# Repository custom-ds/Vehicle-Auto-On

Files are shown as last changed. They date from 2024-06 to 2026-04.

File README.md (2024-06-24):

# Vehicle Auto-On #

## Source ##

### Configuring the Dev Environment ###
Install Platform IO in Visual Studio Code

Use the jtag2updi

https://dev.to/dariocasciato/attiny85-programming-your-complete-guide-with-arduino-and-platformio-37do

https://www.electronics-lab.com/project/programming-attiny10-platform-io-ide/

### Programming ###

With the Arduion programmer board loaded with the jtag2updi software, and the Pin 6 from the Arduino connected to the Reset
line on the ATTiny404, you can Build and Program directly inside of the Visual Studio Code.

To build, go to the bottom-left part of the screen to the Status Bar area of VSCode, and there should be some little icons
that Platform IO installed. The Checkmark icon is the Build option, and will compile/build the code that is written.

Once it compiles successfully, there is a second icon that is a right-arrow to click, which will utilize the Arduino
programmer to program the ATTiny via UPDI.

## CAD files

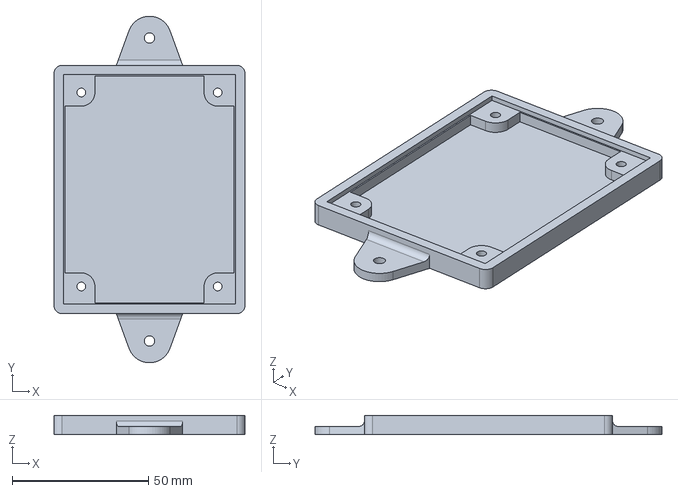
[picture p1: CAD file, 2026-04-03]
Case/Vehicle Power.FCStd
70.0 x 127.0 x 7.00 mm

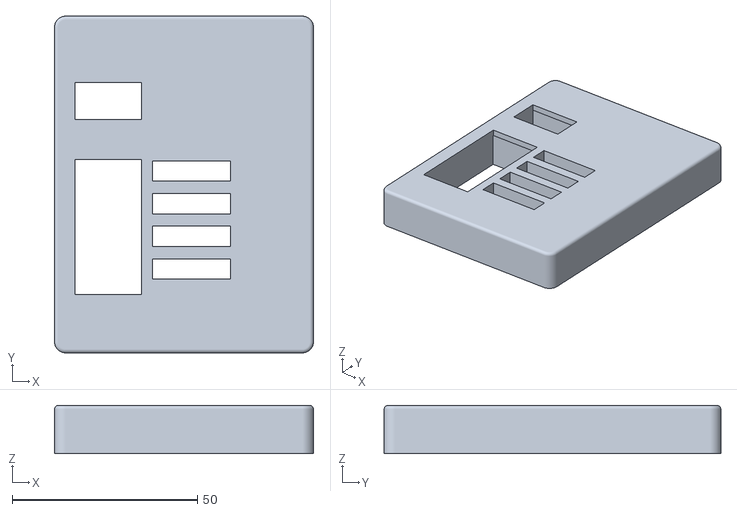
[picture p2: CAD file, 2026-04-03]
Case/housing-top - no cutouts.stl
70.0 x 91.0 x 13.0

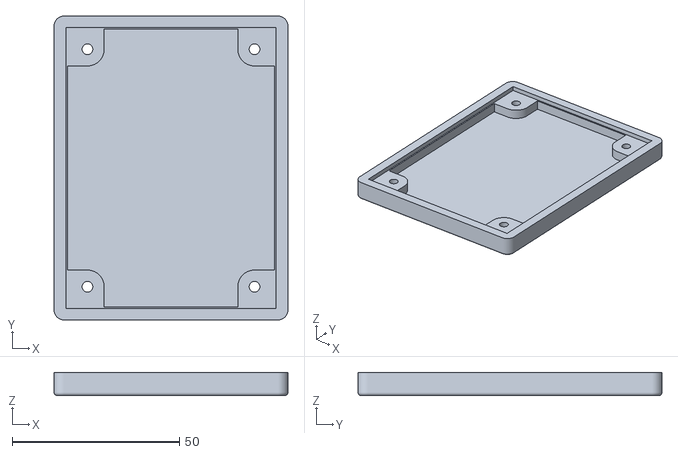
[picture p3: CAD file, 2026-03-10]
Case/housing-bottom.stl
70.0 x 91.0 x 7.00

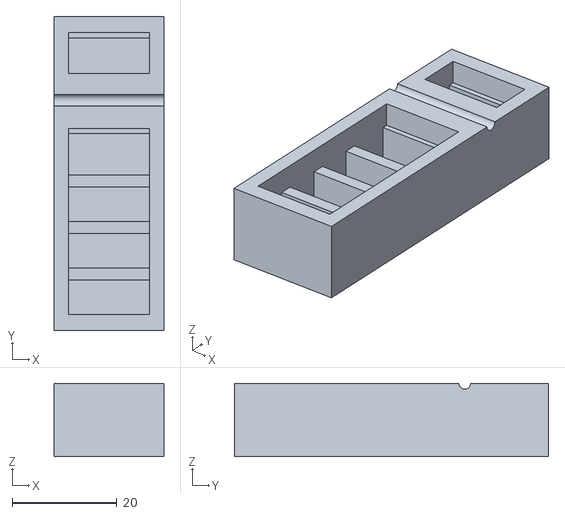
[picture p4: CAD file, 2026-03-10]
Case/alignment-jig.stl
21.0 x 60.0 x 14.0

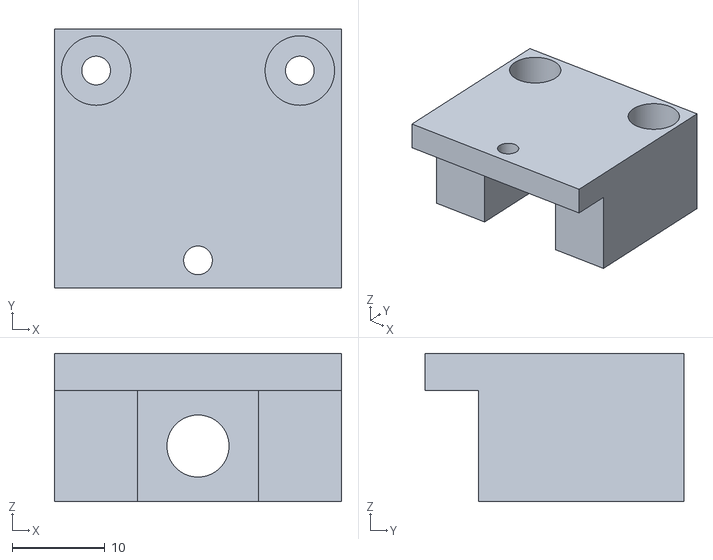
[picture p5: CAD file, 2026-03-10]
Case/switch-front.stl
31.0 x 28.0 x 16.0

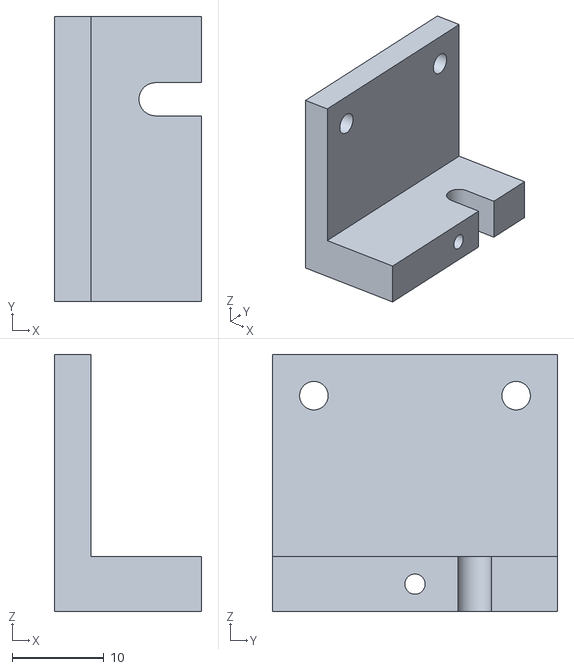
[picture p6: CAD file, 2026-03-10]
Case/switch-back.stl
16.0 x 31.0 x 28.0

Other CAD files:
Case/housing-bottom-with-tab.stl
Case/housing-top.stl

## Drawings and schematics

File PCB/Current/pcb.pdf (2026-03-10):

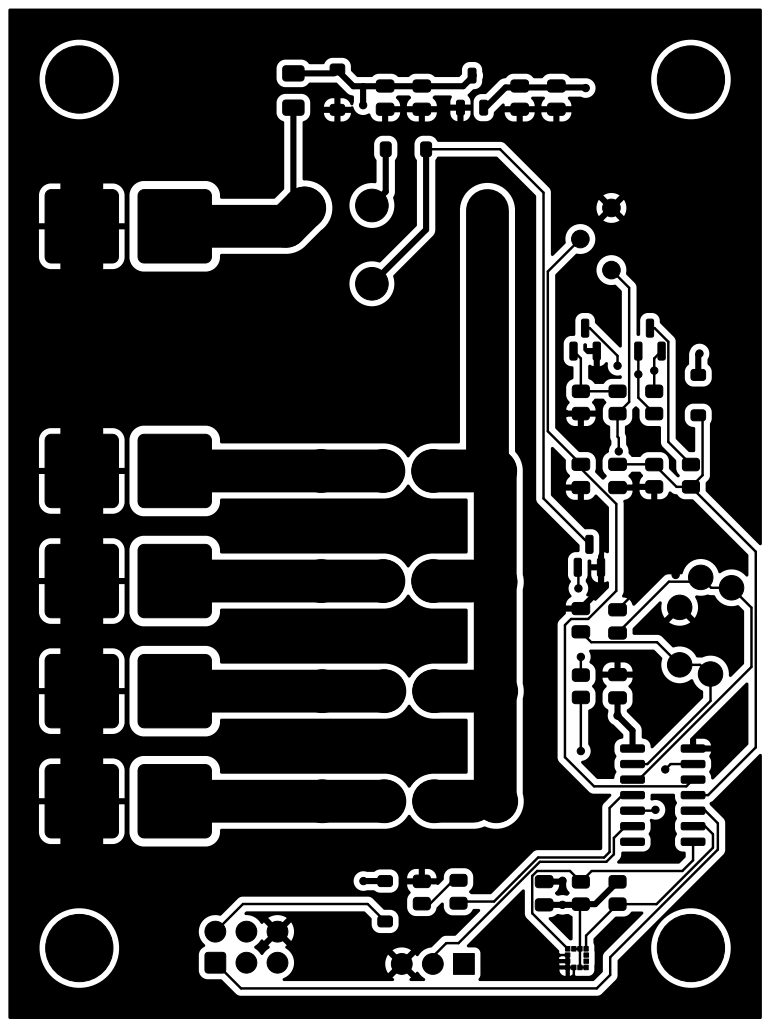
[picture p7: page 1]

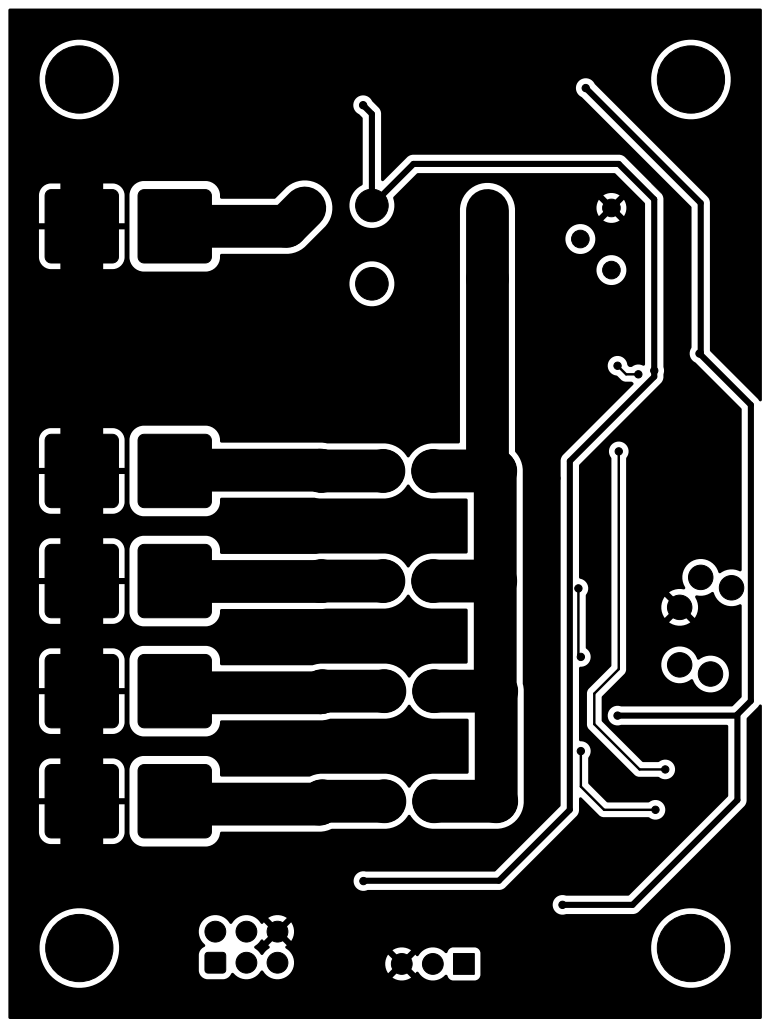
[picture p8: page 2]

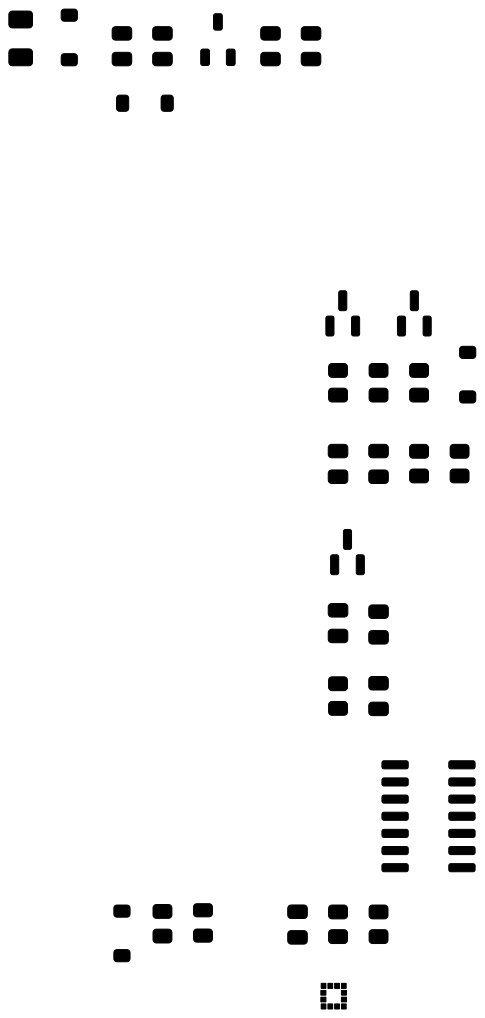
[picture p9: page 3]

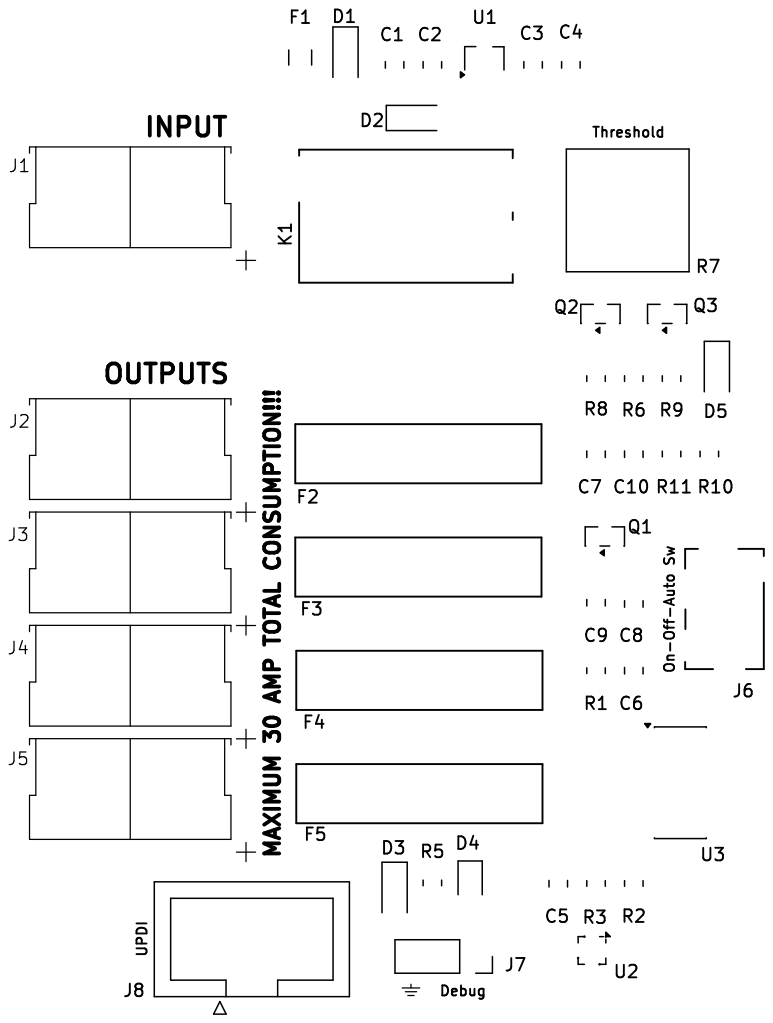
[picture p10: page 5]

MAXIMUM 30 AMP TOTAL CONSUMPTION!!! UPDI Threshold OUTPUTS On-Off-Auto Sw

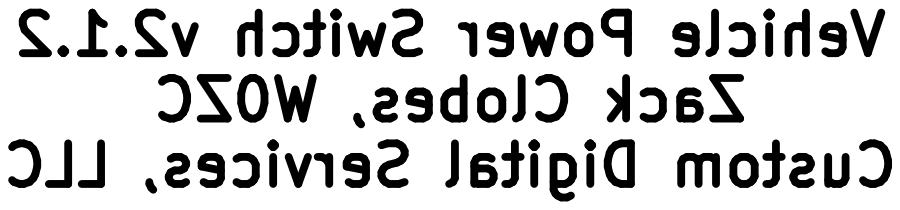
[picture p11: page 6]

v2.1.2 Switch Power Vehicle W0ZC Clobes, Zack LLC Services, Digital Custom

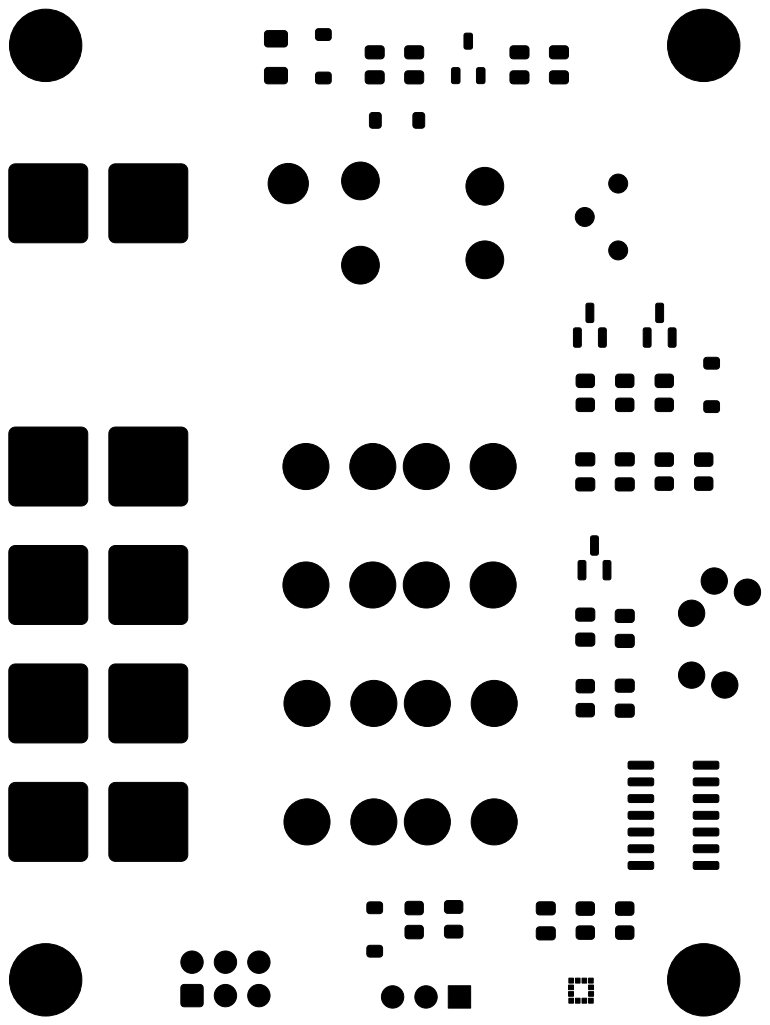
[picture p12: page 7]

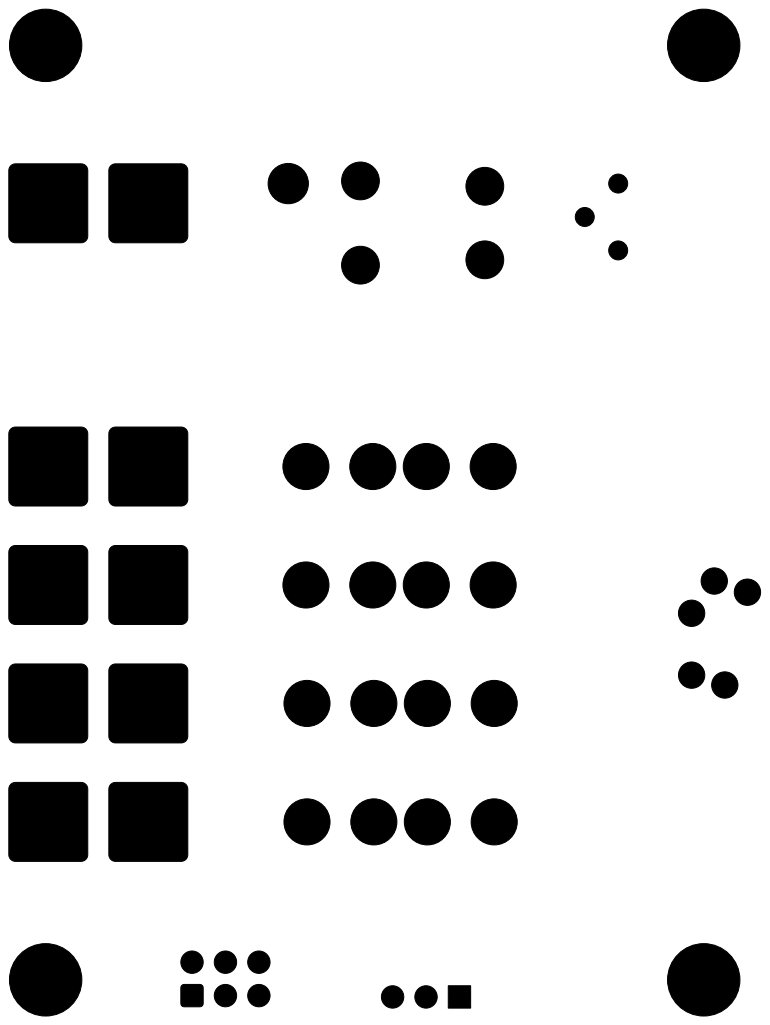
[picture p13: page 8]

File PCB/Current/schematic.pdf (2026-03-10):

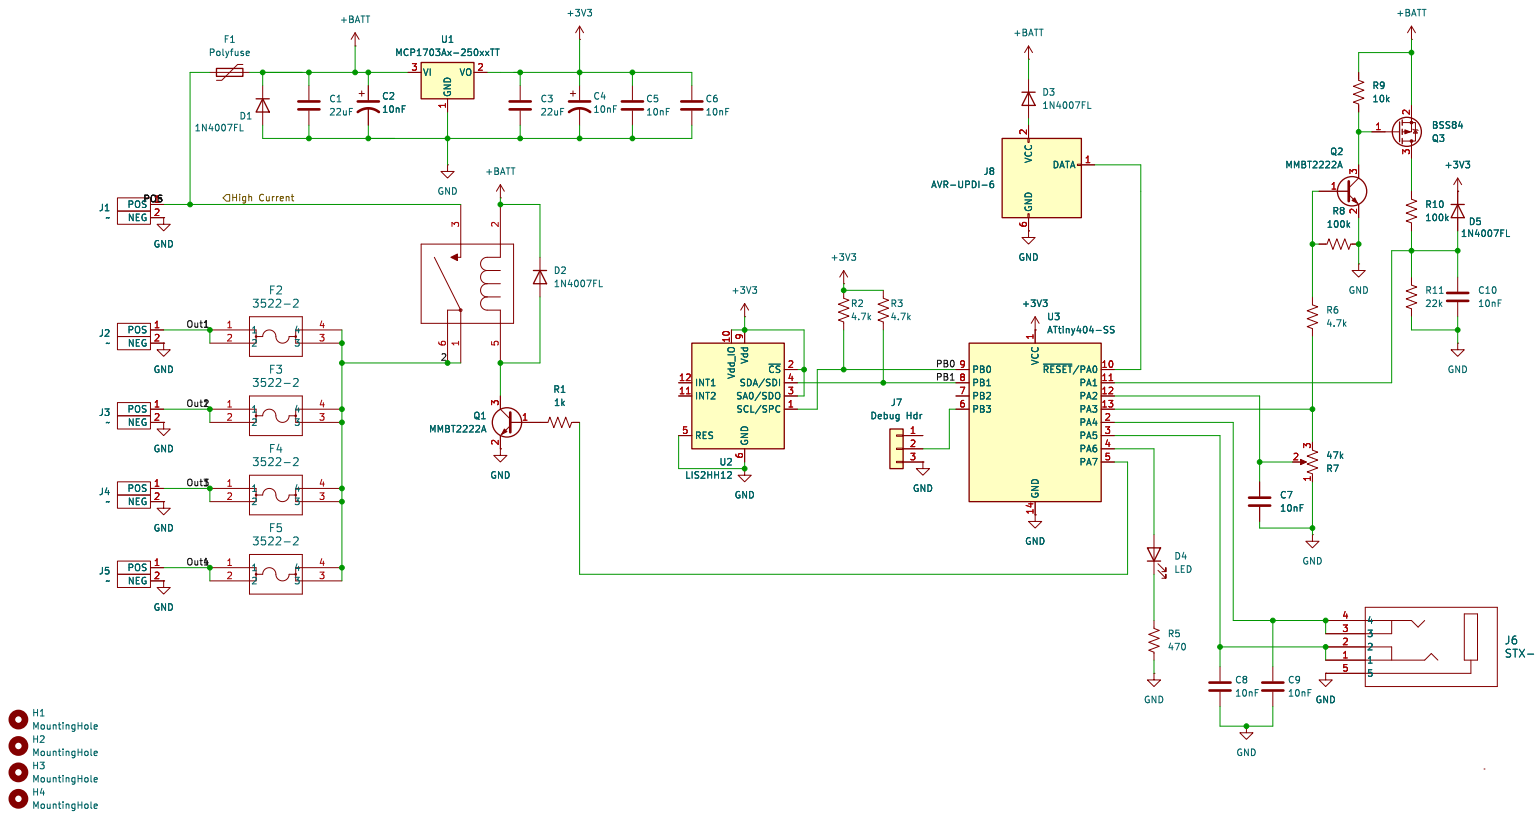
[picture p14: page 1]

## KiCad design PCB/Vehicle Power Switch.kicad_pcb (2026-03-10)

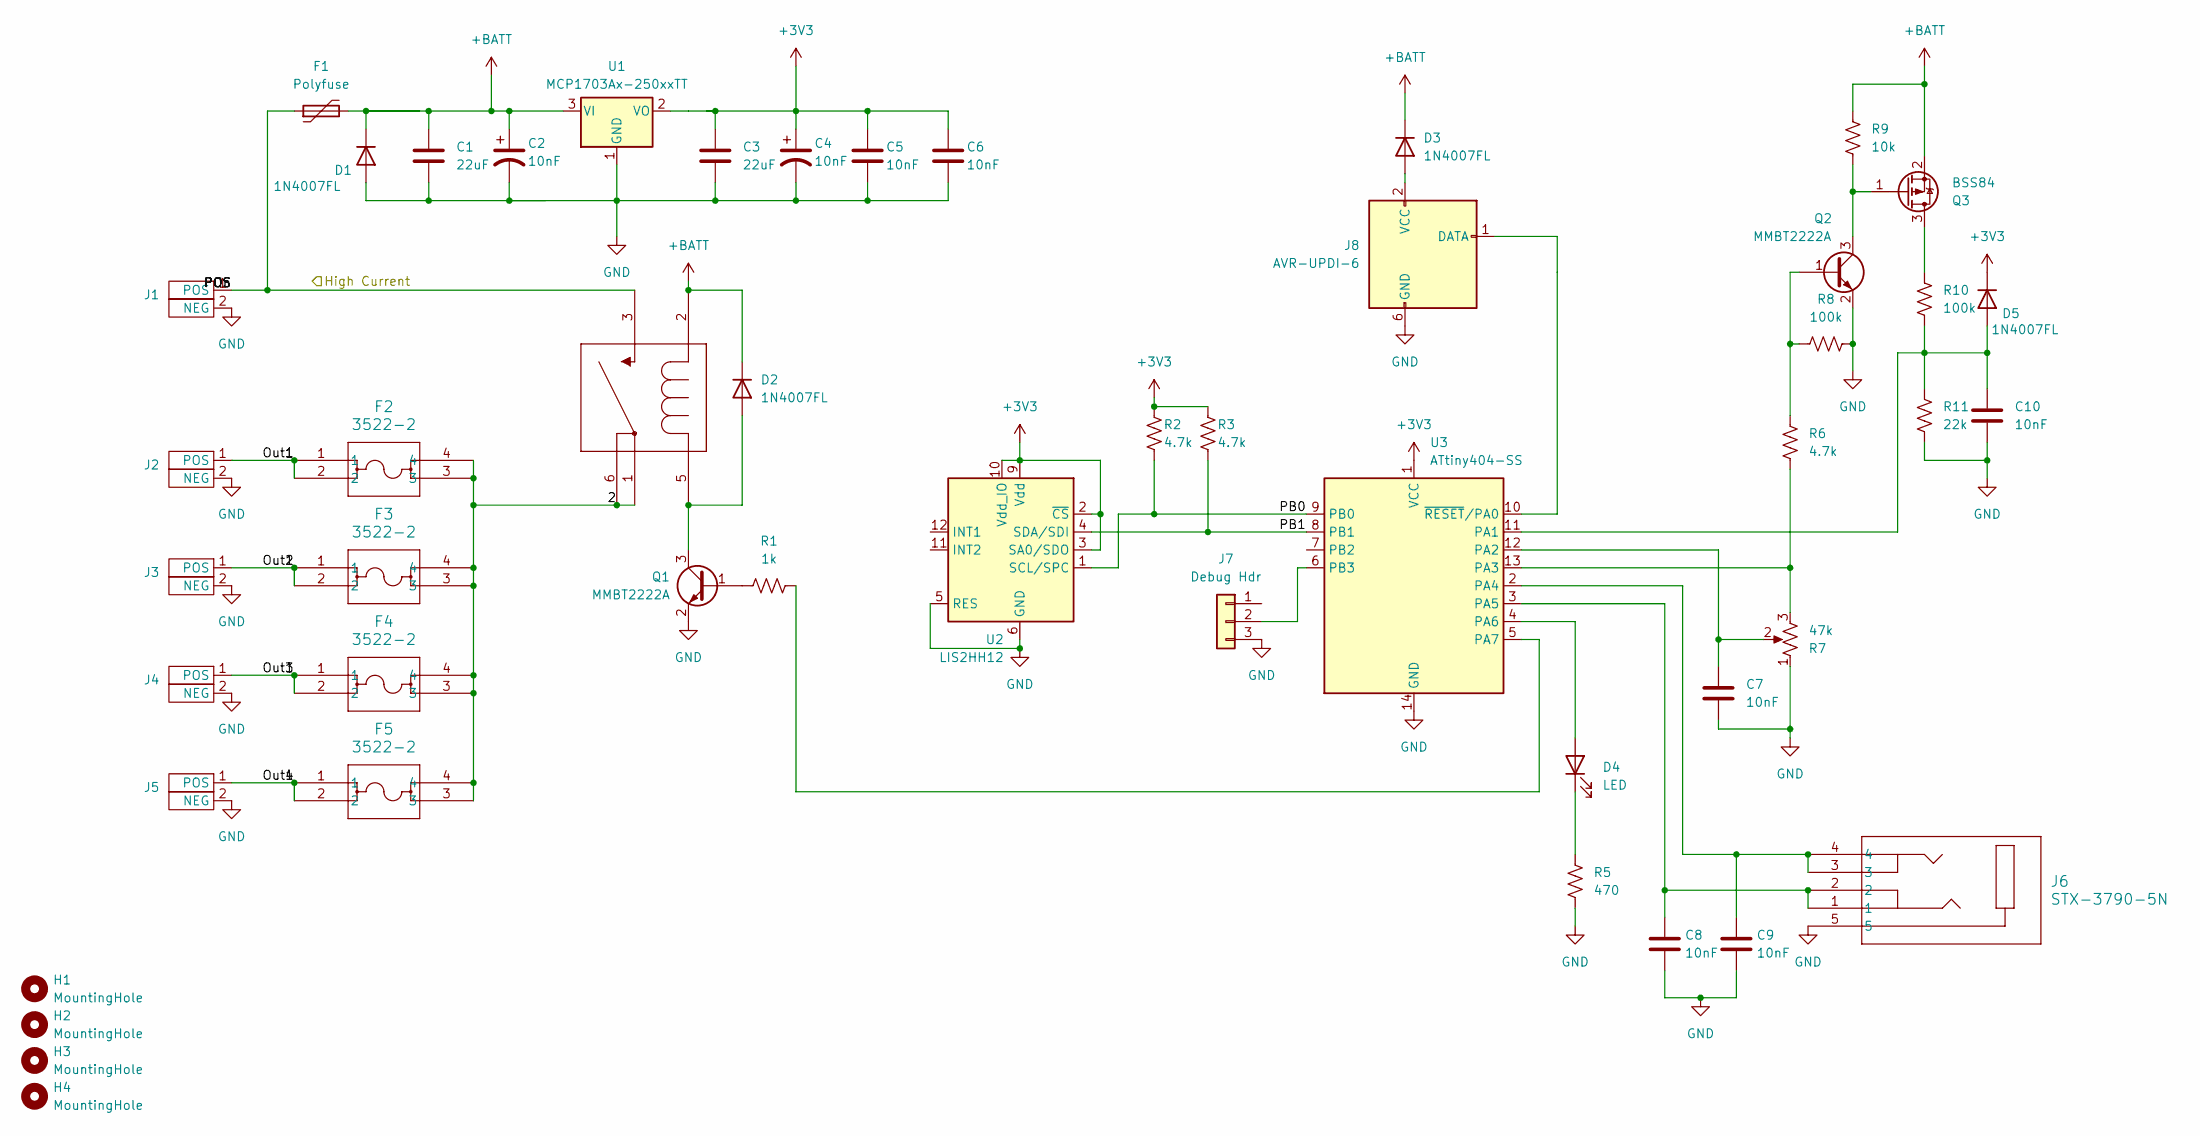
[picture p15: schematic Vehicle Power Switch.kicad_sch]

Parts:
C1, C3: 22uF; C_0805_2012Metric; Digikey 13-CC0805MFX5R8BB226CT-ND
C2, C4, C5, C6, C7, C8, C9, C10: 10nF; C_0805_2012Metric; Digikey 399-1158-1-ND
D1, D2, D3, D5: 1N4007FL; D_SOD-123; Digikey 1655-1N4007FLCT-ND
D4: LED; LED_0805_2012Metric
F1: Polyfuse; Fuse_1206_3216Metric; Digikey 507-1794-1-ND
F2, F3, F4, F5: 3522-2; Fuse Clip Blade - 3522-2; Digikey 36-3522-2-ND
H1, H2, H3, H4: MountingHole; MountingHole_3.2mm_M3_ISO14580_Pad
J1, J2, J3, J4, J5: Anderson Powerpole Vertical
J6: STX-3790-5N; Stereo Jack Vertical - STX-3790-5N; Digikey 2092-STX-3790-5N-ND
J7: Debug Hdr; PinSocket_1x03_P2.54mm_Vertical
J8: AVR-UPDI-6; IDC-Header_2x03_P2.54mm_Vertical
K1: 12V Relay - ACNH; Digikey 255-2583-ND
Q1, Q2: MMBT2222A; SOT-23; Digikey 4878-MMBT2222ATR-ND
Q3: BSS84; SOT-23; Digikey BSS84CT-ND
R1: 1k; R_0805_2012Metric
R2, R3, R6: 4.7k; R_0805_2012Metric
R5: 470; R_0805_2012Metric
R7: 47k; Potentiometer_Bourns_3386P_Vertical; Digikey 3386P-1-473LF-ND
R8, R10: 100k; R_0805_2012Metric
R9: 10k; R_0805_2012Metric
R11: 22k; R_0805_2012Metric
U1: MCP1703Ax-250xxTT; TSOT-23; Digikey MCP1703AT-3302E/CB
U2: LIS2HH12; LGA-12_2x2mm_P0.5mm; Digikey 497-15069-1-ND
U3: ATtiny404-SS; SOIC-14_3.9x8.7mm_P1.27mm; Digikey ATTINY404-SSFRTR-ND

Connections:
+3V3: C3.1, C4.1, C5.1, C6.1, D5.1 (K), R2.1, R3.1, U1.2 (VO), U2.2 (~CS), U2.3 (SA0/SDO), U2.9 (Vdd), U2.10 (Vdd_IO), U3.1 (VCC)
+BATT: C1.1, C2.1, D1.1 (K), D2.1 (K), D3.1 (K), F1.2, K1.2 (5), Q3.2 (S), R9.1, U1.3 (VI)
/1: F2.1, F2.2, F3.1, F3.2, F4.1, F4.2, F5.1, F5.2, J2.1 (POS), J3.1 (POS), J4.1 (POS), J5.1 (POS)
/2: F2.3, F2.4, F3.3, F3.4, F4.3, F4.4, F5.3, F5.4, K1.1 (4), K1.6 (2)
/In: F1.1, J1.1 (POS), K1.3
/PB0: R2.2, U2.1 (SCL/SPC), U3.9 (PB0)
/PB1: R3.2, U2.4 (SDA/SDI), U3.8 (PB1)
GND: C1.2, C2.2, C3.2, C4.2, C5.2, C6.2, C7.2, C8.2, C9.2, C10.2, D1.2 (A), J1.2 (NEG), J2.2 (NEG), J3.2 (NEG), J4.2 (NEG), J5.2 (NEG), J6.5, J7.3, J8.6 (GND), Q1.2 (E), Q2.2 (E), R5.2, R7.1, R8.2, R11.2, U1.1 (GND), U2.5 (RES), U2.6 (GND), U2.7 (GND), U2.8 (GND), U3.14 (GND)
unnamed: D2.2 (A), K1.5 (1), Q1.3 (C)
unnamed: D3.2 (A), J8.2 (VCC)
unnamed: D4.2 (A), U3.4 (PA6)
unnamed: D4.1 (K), R5.1
unnamed: C10.1, D5.2 (A), R10.2, R11.1, U3.11 (PA1)
unnamed: J7.2, U3.6 (PB3)
unnamed: J8.1 (DATA), U3.10 (~RESET/PA0)
unnamed: Q1.1 (B), R1.1
unnamed: Q2.1 (B), R6.1, R8.1
unnamed: Q2.3 (C), Q3.1 (G), R9.2
unnamed: Q3.3 (D), R10.1
unnamed: C7.1, R7.2, U3.12 (PA2)
unnamed: R6.2, R7.3, U3.13 (PA3)
unnamed: C9.1, J6.3, J6.4, U3.2 (PA4)
unnamed: C8.1, J6.1, J6.2, U3.3 (PA5)
unnamed: R1.2, U3.5 (PA7)

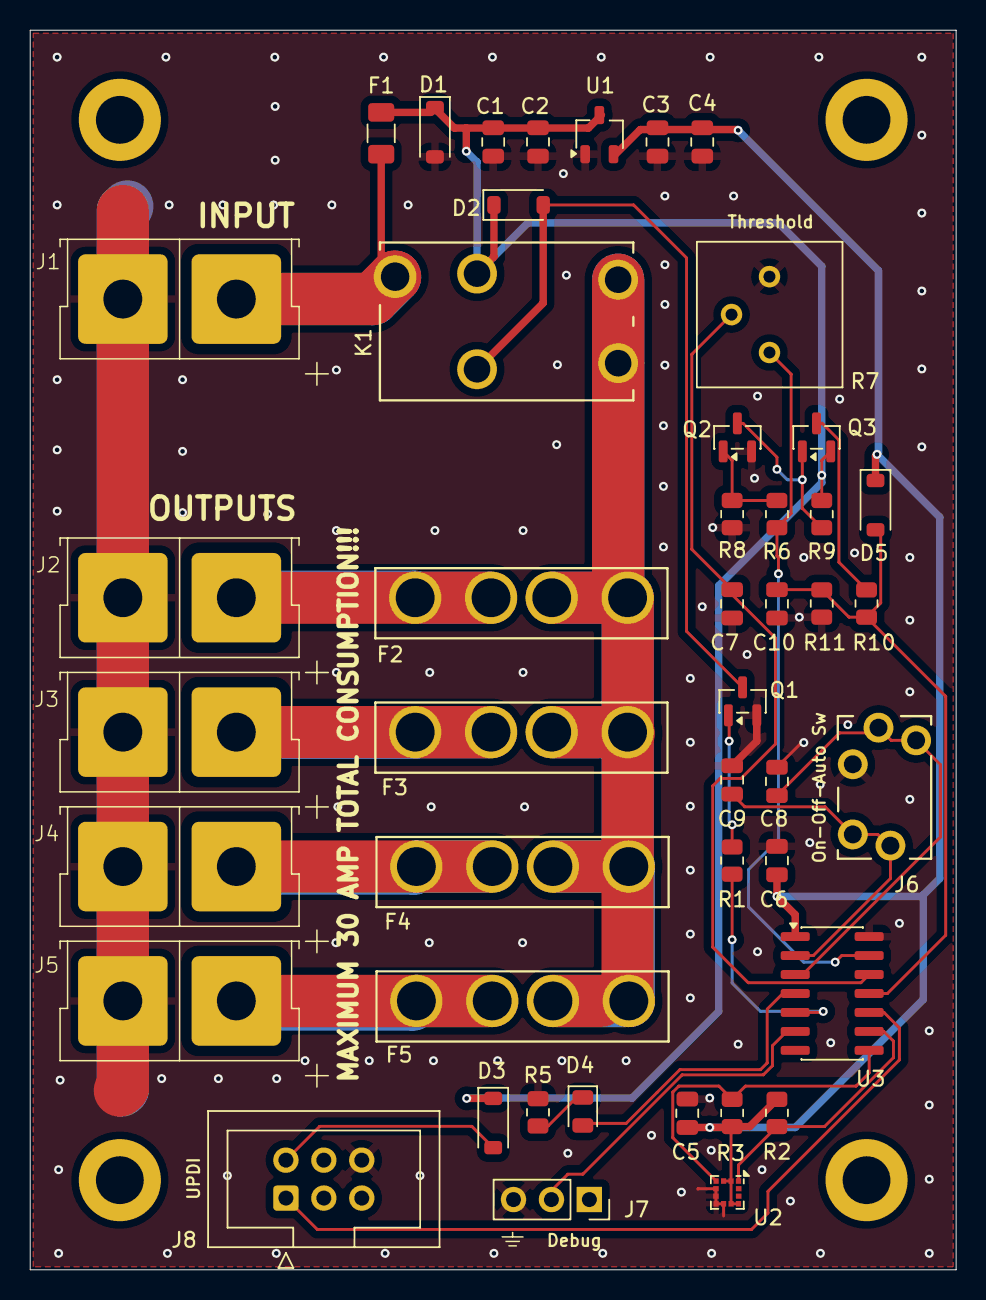
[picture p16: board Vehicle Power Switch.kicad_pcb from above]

Board: 2 copper layers, 62.0 x 83.0 mm, 49 parts (0 on the bottom side), 24 nets.

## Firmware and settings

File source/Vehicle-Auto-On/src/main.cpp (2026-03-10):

#include <avr/io.h>
#include <Arduino.h>
#include <Wire.h>
#include <avr/sleep.h>
#include <avr/power.h>
#include <avr/wdt.h>
//include <avr/pgmspace.h>

#define F_CPU 3333333U



//Outputs
#define LED_STATUS PIN_PA6
#define ANALOG_ENABLE PIN_PA3
#define RELAY PIN_PA7


//Digital Inputs
#define SWITCH_AUTO PIN_PA4
#define SWITCH_ON PIN_PA5

//Analog Inputs
#define ANALOG_BATTERY_LEVEL PIN_PA1
#define ANALOG_REFERENCE PIN_PA2

//Software Serial pins
#define DEBUG_SERIAL
#define SOFT_SERIAL_TX PIN_PB3

//Constants
#define MAX_COUNDOWN 2400   //Half-second intervals to keep the relay on after losing battery voltage sense. Set to 20 minutes (2400 * 0.5s)
//define MAX_COUNDOWN 10   //Half-second intervals to keep the relay on after losing battery voltage sense --- IGNORE ---
#define SWITCH_POSITION_DELAY 3

// How many cycles to wait between events. Each cycle is about 300mS

#define CHECK_AUTO_INTERVAL 9   //Number of loop cycles between auto-checks for charging/motion. 9 = 3.0 seconds
#define AUTO_SHUTDOWN_DELAY 1800 //Number of cycles to wait before auto-shutdown when not charging or in motion. 1800 = about 10 minutes. Set to 30 for debugging


// LIS2HH12 accelerometer constants
#define LIS2HH12_I2C_ADDRESS 0x1D  // Default I2C address (can also be 0x1D depending on SA0 pin) (0x1E is default, 0x1D if SA0 is grounded)
#define LIS2HH12_WHO_AM_I 0x0F
#define LIS2HH12_CTRL1 0x20
#define LIS2HH12_CTRL2 0x21
#define LIS2HH12_CTRL3 0x22
#define LIS2HH12_OUT_X_L 0x28
#define LIS2HH12_OUT_X_H 0x29
#define LIS2HH12_OUT_Y_L 0x2A
#define LIS2HH12_OUT_Y_H 0x2B
#define LIS2HH12_OUT_Z_L 0x2C
#define LIS2HH12_OUT_Z_H 0x2D

// Motion detection threshold (adjust based on sensitivity needs)
#define MOTION_THRESHOLD 100  // Raw acceleration difference threshold
#define MOTION_SAMPLES 3      // Number of samples to compare for motion detection


// Define the timer frequency (1 Hz)
const uint32_t timerFrequency = 1; // 1 Hz

// Global variables for motion detection
int16_t prevAccelX = 0, prevAccelY = 0, prevAccelZ = 0;
bool accelInitialized = false;

// Custom serial configuration
#define CUSTOM_BAUD_RATE 960    //works out to be 1200 baud. The bit-banging is very sensitive to timing errors
#define BIT_DELAY_US (1000000UL / CUSTOM_BAUD_RATE)  // Microseconds per bit

//Enum switch state
enum SwitchState {
  STATE_OFF,
  STATE_ON,
  STATE_AUTO
};

enum LightState {
  LIGHT_OFF,
  LIGHT_ON,
  BLINK_SLOW,
  BLINK_FAST
};


// Function prototypes
bool isCharging();
bool isInMotion();

void setupRTC();
void goToSleep(bool lowPowerMode);

bool initLIS2HH12();
void writeLIS2HH12Register(uint8_t reg, uint8_t value);
uint8_t readLIS2HH12Register(uint8_t reg);
int16_t readLIS2HH12Axis(uint8_t regL, uint8_t regH);

void customSerialInit();
void customSerialWrite(uint8_t data);
void customSerialPrint(const char* str);
void customSerialPrint(uint16_t num);
void customSerialPrintln(const char* str);




ISR(WDT_vect) {
  // WDT interrupt service routine - does nothing, just wakes the MCU
}


void setup()
{
  // initialize LED digital pin as an output.
  pinMode(LED_STATUS, OUTPUT);
  pinMode(ANALOG_ENABLE, OUTPUT);
  pinMode(RELAY, OUTPUT);

  //Configure pullup resistors on the switches
  pinMode(SWITCH_AUTO, INPUT_PULLUP);
  pinMode(SWITCH_ON, INPUT_PULLUP);

  //initialize analog inputs
  pinMode(ANALOG_BATTERY_LEVEL, INPUT);
  pinMode(ANALOG_REFERENCE, INPUT);


  // Initialize custom bit-banged serial on PB2 (TX) and PB3 (RX)
  // Use a lower baud rate for better reliability with ATtiny404 at 3.33MHz
  customSerialInit();  // Initialize custom serial at 1200 baud


  // Initialize the LIS2HH12 accelerometer
  Wire.begin();
  #ifdef DEBUG_SERIAL
  customSerialPrintln("Init");
  #endif

  initLIS2HH12();
  
  #ifdef DEBUG_SERIAL
  customSerialPrintln("OK");
  #endif

  setupRTC();
}




void loop() {
  SwitchState nextPosition;

  //static vars to survive the sleep cycles
  static LightState ledMode;
  static uint16_t nextPositionDelay = 0;
  static uint16_t autoReaffirm = 0;
  static uint16_t autoKeepAliveCount = 0;
  static uint16_t ledCount = 0;

  static int autoCountdown;
  static bool lowPower = false;


  //Check the switch state
  pinMode(SWITCH_AUTO, INPUT_PULLUP);
  pinMode(SWITCH_ON, INPUT_PULLUP);  


  //Assume it's safe to go into low-power mode
  lowPower = true;


  //Determine the switch position
  if (digitalRead(SWITCH_AUTO) == HIGH && digitalRead(SWITCH_ON) == HIGH) {
    //both high, so it's in the off position
    if (nextPosition != STATE_OFF) {
      nextPosition = STATE_OFF;
      nextPositionDelay = SWITCH_POSITION_DELAY; //delay 5 cycles before changing state
    }
  } else if (digitalRead(SWITCH_ON) == LOW) {
    //Switch is in the manual on position
    if (nextPosition != STATE_ON) {
      nextPosition = STATE_ON;
      nextPositionDelay = SWITCH_POSITION_DELAY; //delay 5 cycles before changing state
    }
  } else if (digitalRead(SWITCH_AUTO) == LOW) {
    //Switch is in auto position
    if (nextPosition != STATE_AUTO) {
      nextPosition = STATE_AUTO;
      nextPositionDelay = SWITCH_POSITION_DELAY; //delay 5 cycles before changing state
    }
  }
  


  if (nextPositionDelay > 0) {
    nextPositionDelay--;
  } else {
    //it's time to make a move

    switch (nextPosition) {
    case STATE_OFF:
      // Turn off the relay and LED
      #ifdef DEBUG_SERIAL
      customSerialPrintln("0");
      #endif

      digitalWrite(RELAY, LOW);
      ledMode = LIGHT_OFF;
      ledCount = 0;
      lowPower = true;    // allow it to go into low power mode

      autoKeepAliveCount = 0;  //reset the auto keep-alive counter

      break;
    case STATE_ON:
      // Turn on the relay and LED
      #ifdef DEBUG_SERIAL
      customSerialPrintln("1");
      #endif

      digitalWrite(RELAY, HIGH);
      ledMode = LIGHT_ON;
      ledCount = 0;
      lowPower = false;   //stay awake when manually on

      autoKeepAliveCount = 0;  //reset the auto keep-alive counter

      break;
    case STATE_AUTO:
      // In auto mode, check for battery voltage, and motion if we're already switched on
      #ifdef DEBUG_SERIAL
      customSerialPrintln("A");
      #endif

      if (autoReaffirm > 0) {
        autoReaffirm--;
      } else {
        //it's time to reaffirm if the car is charging/moving
        if (isCharging()) {
          //the car battery is charging - stay awake
          autoReaffirm = CHECK_AUTO_INTERVAL;
          if (ledMode != BLINK_SLOW) {
            ledMode = BLINK_SLOW;
            ledCount = 0;
          }
          //reset the autoKeepAliveCount
          if (autoKeepAliveCount > 0) {
            //we were already on, so just extend the keep-alive
            autoKeepAliveCount = AUTO_SHUTDOWN_DELAY;
          } else {
            //we were off, so set the keep-alive to turn on the relay, but set it to a higher initial value to allow the alternator to stabilize
            autoKeepAliveCount = AUTO_SHUTDOWN_DELAY + 10;
          }

        } else {
          //maybe it's moving but the battery voltage is dropping - this happens on modern cars with smart alternators

          //but make sure that the Auto had previously been woken due to charging, before failing back to motion detection for keep-alive
          #ifdef DEBUG_SERIAL
          customSerialPrint(autoKeepAliveCount);
          customSerialPrintln("");
          #endif

          if (autoKeepAliveCount > 0) {
            #ifdef DEBUG_SERIAL
            customSerialPrintln("M");
            #endif

            if (isInMotion()) {
              //the car is moving - stay awake
              autoReaffirm = CHECK_AUTO_INTERVAL;
              if (ledMode != BLINK_FAST) {
                ledMode = BLINK_FAST;
                ledCount = 0;
              }

              //reset the autoKeepAliveCount
              autoKeepAliveCount = AUTO_SHUTDOWN_DELAY;
            } else {
              // Not charging and not in motion - start the shutdown process
              ledMode = LIGHT_OFF;
              ledCount = 0;
              autoReaffirm = 3;
            }
          }
        }
      }

      //Check the state of the relay based on the autoKeepAliveCount
      if (autoKeepAliveCount > 0) {
        autoKeepAliveCount--;   //decrement the keep-alive counter while it's positive
        // see if we're over the max countdown, which indicates that we're waiting a couple of seconds for the alternator to stabilize before energizing the relay
        if (autoKeepAliveCount <= AUTO_SHUTDOWN_DELAY) {
          //we're witin the normal operating range, so energize the relay
          digitalWrite(RELAY, HIGH);
        }
        
        lowPower = false;   //stay awake while the relay is on
      } else {
        digitalWrite(RELAY, LOW);
        lowPower = true;    //allow low power mode when the relay is off
      }

      break;
    }


    int8_t currentLEDState = digitalRead(LED_STATUS);
    //Check the LED Blink Status
    if (ledCount == 0) {
      //it's time to cycle the LED
      switch (ledMode) {
      case LIGHT_OFF:
        digitalWrite(LED_STATUS, LOW);
        ledCount = 0xFFFF; //stay off for quite a while
        break;
      case LIGHT_ON:
        digitalWrite(LED_STATUS, HIGH);
        ledCount = 0xFFFF; //stay on for quite a while
        break;
      case BLINK_SLOW:
        digitalWrite(LED_STATUS, !currentLEDState);
        ledCount = 6; //slow blink
        break;
      case BLINK_FAST:
        digitalWrite(LED_STATUS, !currentLEDState);
        ledCount = 2; //fast blink
        break;
      }

    } else {
      ledCount--;
    }

  }



  customSerialPrint(lowPower);
  customSerialPrintln("");
  goToSleep(lowPower);
}

ISR(RTC_CNT_vect) {
  RTC.INTFLAGS = RTC_OVF_bm; // clear flag
}

ISR(RTC_PIT_vect) {
  RTC.PITINTFLAGS = RTC_PI_bm; // clear PIT interrupt flag
}



void setupRTC() {
  while (RTC.STATUS > 0) {}               // wait for sync
  RTC.CLKSEL = RTC_CLKSEL_INT32K_gc;      // 32.768 kHz internal ULP oscillator
  RTC.PITINTCTRL = RTC_PI_bm;             // enable PIT interrupt
  //RTC.PITCTRLA   = RTC_PERIOD_CYC32768_gc | RTC_PITEN_bm;        // start PIT   // About 1 second
  //RTC.PITCTRLA   = RTC_PERIOD_CYC16384_gc | RTC_PITEN_bm;        // start PIT   // About 500mS
  RTC.PITCTRLA   = RTC_PERIOD_CYC8192_gc | RTC_PITEN_bm;        // start PIT    // About 250mS
}


void goToSleep(bool lowPowerMode) {

  if (lowPowerMode) {
    set_sleep_mode(SLEEP_MODE_PWR_DOWN);
    sleep_enable();
    sei();
    sleep_cpu();
    sleep_disable();
  } else {
    delay(250);
  }

}


bool isCharging() {

  uint16_t battery, reference;

  //read the analog inputs
  digitalWrite(ANALOG_ENABLE, HIGH);    //enable the analog circuitry

  battery = analogRead(ANALOG_BATTERY_LEVEL);
  reference = analogRead(ANALOG_REFERENCE);

  //turn off the analog enable pin
  digitalWrite(ANALOG_ENABLE, LOW);

  //Convert to millivolts
  //battery = (float)(battery * 1);  //Show the raw value for debugging
  battery = (float)(battery * 18.32);// + 308;   //approximate battery voltage in mV 18.31
  if (digitalRead(RELAY) == HIGH) {
    //the relay is on, so the offset voltage is elevated due to voltage drop across resettable fuse
    battery += 568;
  } else {
    battery += 320;
  }
  
  reference = (reference * 2) + 12000; //approximate reference voltage in mV

  #ifdef DEBUG_SERIAL
  customSerialPrint("Bat ");
  customSerialPrint(battery);
  customSerialPrint(" / ");
  customSerialPrint(reference);
  customSerialPrintln("");
  return (battery > reference);
  #endif
}



// Helper function to write to LIS2HH12 register
void writeLIS2HH12Register(uint8_t reg, uint8_t value) {
  Wire.beginTransmission(LIS2HH12_I2C_ADDRESS);
  Wire.write(reg);
  Wire.write(value);
  Wire.endTransmission();
}

// Helper function to read from LIS2HH12 register
uint8_t readLIS2HH12Register(uint8_t reg) {
  Wire.beginTransmission(LIS2HH12_I2C_ADDRESS);
  Wire.write(reg);
  Wire.endTransmission(false);

  Wire.requestFrom(LIS2HH12_I2C_ADDRESS, 1);
  if (Wire.available()) {
    return Wire.read();
  }
  return 0;
}

// Helper function to read 16-bit accelerometer data
int16_t readLIS2HH12Axis(uint8_t regL, uint8_t regH) {
  uint8_t low = readLIS2HH12Register(regL);
  uint8_t high = readLIS2HH12Register(regH);
  return (int16_t)((high << 8) | low);
}

// Initialize the LIS2HH12 accelerometer
bool initLIS2HH12() {
  // Check WHO_AM_I register
  uint8_t whoAmI = readLIS2HH12Register(LIS2HH12_WHO_AM_I);
  customSerialPrint(whoAmI);

  if (whoAmI != 0x41) {  // Expected WHO_AM_I value for LIS2HH12
    return false;
  }
  
  // Configure CTRL1 register: Enable X, Y, Z axes, set data rate to 10Hz
  writeLIS2HH12Register(LIS2HH12_CTRL1, 0x17); // 0001 0111: 10Hz, XYZ enabled
  
  // Configure CTRL2 register: +/- 2g full scale
  writeLIS2HH12Register(LIS2HH12_CTRL2, 0x00); // 0000 0000: +/- 2g
  
  // Configure CTRL3 register: Default settings
  writeLIS2HH12Register(LIS2HH12_CTRL3, 0x00);
  
  delay(100); // Allow time for configuration
  
  // Read initial values
  prevAccelX = readLIS2HH12Axis(LIS2HH12_OUT_X_L, LIS2HH12_OUT_X_H);
  prevAccelY = readLIS2HH12Axis(LIS2HH12_OUT_Y_L, LIS2HH12_OUT_Y_H);
  prevAccelZ = readLIS2HH12Axis(LIS2HH12_OUT_Z_L, LIS2HH12_OUT_Z_H);
  
  accelInitialized = true;
  #ifdef DEBUG_SERIAL
  customSerialPrintln("a");
  #endif
  return true;
}

bool isInMotion() {
  //Check the LIS2HH12 accelerometer for motion

  if (!accelInitialized) {
    return false; // Accelerometer not initialized
  }

  
  // Read current acceleration values
  int16_t currentAccelX = readLIS2HH12Axis(LIS2HH12_OUT_X_L, LIS2HH12_OUT_X_H);
  int16_t currentAccelY = readLIS2HH12Axis(LIS2HH12_OUT_Y_L, LIS2HH12_OUT_Y_H);
  int16_t currentAccelZ = readLIS2HH12Axis(LIS2HH12_OUT_Z_L, LIS2HH12_OUT_Z_H);
  
  // Debug output
  #ifdef DEBUG_SERIAL
  customSerialPrint(currentAccelX);
  customSerialPrint(" ");
  customSerialPrint(currentAccelY);
  customSerialPrint(" ");
  customSerialPrint(currentAccelZ);
  customSerialPrintln("");
  #endif

  // Calculate the difference from previous readings
  int16_t deltaX = abs(currentAccelX - prevAccelX);
  int16_t deltaY = abs(currentAccelY - prevAccelY);
  int16_t deltaZ = abs(currentAccelZ - prevAccelZ);
  
  // Check if any axis exceeds the motion threshold
  bool motionDetected = (deltaX > MOTION_THRESHOLD) || (deltaY > MOTION_THRESHOLD) || (deltaZ > MOTION_THRESHOLD);
  
  // Update previous values for next comparison
  prevAccelX = currentAccelX;
  prevAccelY = currentAccelY;
  prevAccelZ = currentAccelZ;
  
  return motionDetected;
}

// Custom bit-banged serial implementation
void customSerialInit() {
  pinMode(SOFT_SERIAL_TX, OUTPUT);
  digitalWrite(SOFT_SERIAL_TX, HIGH);  // Idle state is HIGH
  delayMicroseconds(BIT_DELAY_US * 2); // Let line settle
}

void customSerialWrite(uint8_t data) {

  // Start bit (LOW)
  digitalWrite(SOFT_SERIAL_TX, LOW);
  delayMicroseconds(BIT_DELAY_US);
  
  // Data bits (LSB first)
  for (int i = 0; i < 8; i++) {
    digitalWrite(SOFT_SERIAL_TX, (data >> i) & 0x01);
    delayMicroseconds(BIT_DELAY_US);
  }
  
  // Stop bit (HIGH)
  digitalWrite(SOFT_SERIAL_TX, HIGH);
  delayMicroseconds(BIT_DELAY_US);
}

void customSerialPrint(const char* str) {
  while (*str) {
    customSerialWrite(*str++);
  }
}

void customSerialPrint(uint16_t num) {
  char buffer[6]; // Enough for 5 digits + null terminator
  itoa(num, buffer, 10);
  customSerialPrint(buffer);
}

void customSerialPrintln(const char* str) {
  customSerialPrint(str);
  customSerialWrite('\r');
  customSerialWrite('\n');
}

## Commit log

2024-06-24 Initial Commit
    PCB version 2.0 is done. Source is stubbed in.
    [Vehicle Power Switch-B_Cu.gbr, Vehicle Power Switch-B_Mask.gbr, Vehicle Power Switch-B_Paste.gbr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]
2025-10-06 Fixes to PCB v2 and working on firmware.
    [Vehicle Power Switch.kicad_pcb, Vehicle Power Switch.kicad_sch]
2025-12-15 All functionality is working on the prototype. Firmware is still rough.
    [Vehicle Power Switch-B_Cu.gbr, Vehicle Power Switch-B_Mask.gbr, Vehicle Power Switch-B_Paste.gbr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]
2025-12-16 Low power testing showing 100uA during low power loop.
2026-03-10 Release candidate for firmware.
    [Vehicle Power Switch.kicad_pcb, Vehicle Power Switch.kicad_sch, Vehicle Power.FCStd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]
2026-04-03 Added option for case top with no penetrations (for simple power-strip functionality)
    [Vehicle Power.FCStd, housing-bottom-with-tab.stl, housing-top - no cutouts.stl]
2026-10-29 Fixes for intermittent issues with the switch stuck staying on or off.
